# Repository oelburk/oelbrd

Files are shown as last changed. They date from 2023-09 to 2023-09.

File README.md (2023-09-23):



<!-- PROJECT SHIELDS -->
[][contributors-url]
[][forks-url]
[][stars-url]
[][issues-url]
[][license-url]

<!-- PROJECT LOGO -->
<br />
<div align="center">
  <a href="https://github.com/oelburk/oelbrd">
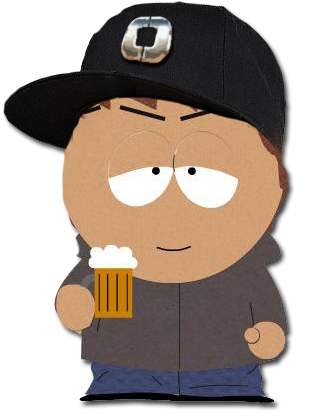
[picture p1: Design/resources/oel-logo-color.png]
    
  </a>

<h3 align="center">OELBRD</h3>

  <p align="center">
    Custom designed keyboard PCB and Firmware
    <br />
    <a href="https://github.com/oelburk/oelbrd/issues">Report Bug</a>
    ·
    <a href="https://github.com/oelburk/oelbrd/issues">Request Feature</a>
  </p>
</div>

<!-- TABLE OF CONTENTS -->
<details>
  <summary>Table of Contents</summary>
  <ol>
    <li>
      <a href="#about-the-project">About The Project</a>
      <ul>
        <li><a href="#built-with">Built With</a></li>
      </ul>
    </li>
    <li>
      <a href="#getting-started">Getting Started (Keymap setup)</a>
      <ul>
        <li><a href="#prerequisites">Prerequisites</a></li>
        <li><a href="#installation">Creating a keymap</a></li>
      </ul>
    </li>
    <li><a href="#contributing">Contributing</a></li>
    <li><a href="#license">License</a></li>
    <li><a href="#acknowledgments">Acknowledgments</a></li>
  </ol>
</details>

<!-- ABOUT THE PROJECT -->
## About The Project

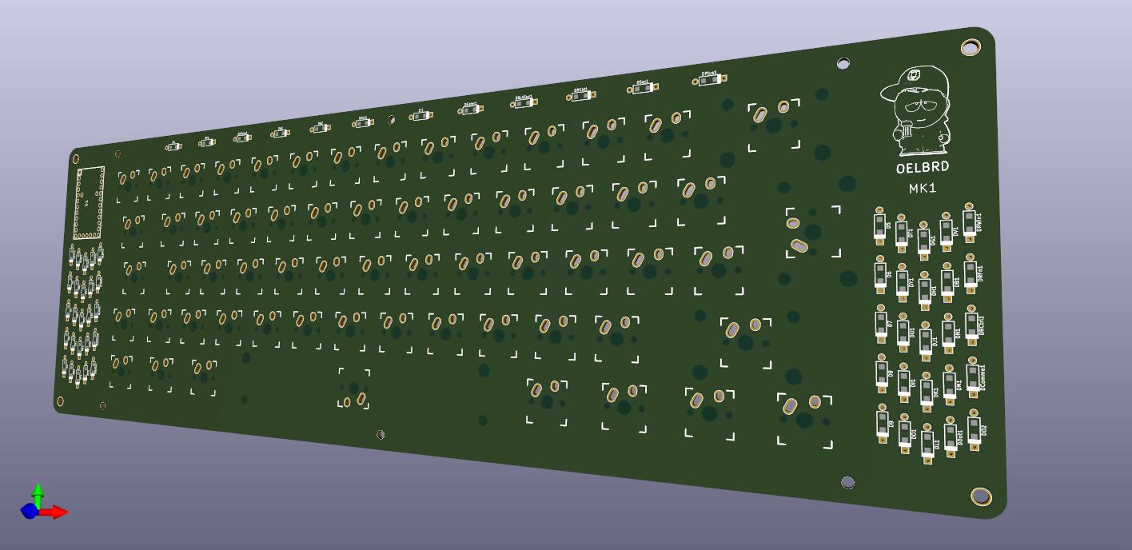
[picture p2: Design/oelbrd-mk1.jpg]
Product Name Screen Shot


Small project containing the PCB design files (KiCad project) along with the source code for different keymaps for my custom designed 60% keyboard.

<p align="right">(<a href="#readme-top">back to top</a>)</p>

### Built With

* [KiCad](https://www.kicad.org/download/windows/)
  * https://github.com/egladman/keebs.pretty
  * https://github.com/tmk/keyboard_parts.pretty
* [QMK](https://qmk.fm/)

<p align="right">(<a href="#readme-top">back to top</a>)</p>

<!-- GETTING STARTED -->
## Getting Started (Keymap setup)

This is an example of how you can create your own keymap for the oelbrd.

### Prerequisites
* Text editor of choice
* [QMK](https://github.com/qmk/qmk_firmware/blob/master/docs/newbs.md)

### Creating a keymap

1. Clone the repo
   ```sh
   git clone https://github.com/oelburk/oelbrd.git
   ```
2. Create new folder in keymaps folder
   ```sh
   mkdir QMK/keymaps/my-keymap
   ```
3. Copy default keymap (optional)
   ```sh
   cp QMK/keymaps/default/keymap.c QMK/keymaps/my-keymap
   ```
4. Edit `keymap.c` with preferred layout
5. Create oelbrd in QMK
   ```sh
   qmk new-keyboard oelbrd
   ```
6. Copy over contents from the QMK folder to new oelbrd directory in QMK repo, usally `../qmk_firmware/keyboards/oelbrd`
7. Compile the new keymap using QMK
   ```sh
   qmk compile -kb oelbrd -kb my-keymap
   ```
8. Flash new layout

### VIA support

There are currently some strange issues with the implemented VIA support, complaining about missing version definitons etc.

To fix this issue:
1. Open `qmk_firware/quantum/via.h`
2. Replace the define `VIA_PROTOCOL_VERSION` at row 62
   ```C
    VIA_PROTOCOL_VERSION 0x0009
   ```
3. Re-compile your keymap.
4. Enjoy VIA!

<p align="right">(<a href="#readme-top">back to top</a>)</p>

<!-- CONTRIBUTING -->
## Contributing

Contributions are what make the open source community such an amazing place to learn, inspire, and create. Any contributions you make are **greatly appreciated**.

If you have a suggestion that would make this better, please fork the repo and create a pull request. You can also simply open an issue with the tag "enhancement".
Don't forget to give the project a star! Thanks again!

1. Fork the Project
2. Create your Feature Branch (`git checkout -b feature/AmazingFeature`)
3. Commit your Changes (`git commit -m 'Add some AmazingFeature'`)
4. Push to the Branch (`git push origin feature/AmazingFeature`)
5. Open a Pull Request

<p align="right">(<a href="#readme-top">back to top</a>)</p>

<!-- LICENSE -->
## License

Distributed under the MIT License. See `LICENSE.txt` for more information.

<p align="right">(<a href="#readme-top">back to top</a>)</p>

<!-- ACKNOWLEDGMENTS -->
## Acknowledgments

* [Shoutout othneildrew for nice README template](https://github.com/othneildrew/Best-README-Template)
* [Swe Mech Keebs Community](http://mekaniskatangentbord.se/)

<p align="right">(<a href="#readme-top">back to top</a>)</p>

<!-- MARKDOWN LINKS & IMAGES -->
<!-- https://www.markdownguide.org/basic-syntax/#reference-style-links -->
[contributors-shield]: https://img.shields.io/github/contributors/oelburk/oelbrd.svg?style=for-the-badge
[contributors-url]: https://github.com/oelburk/oelbrd/graphs/contributors
[forks-shield]: https://img.shields.io/github/forks/oelburk/oelbrd.svg?style=for-the-badge
[forks-url]: https://github.com/oelburk/oelbrd/network/members
[stars-shield]: https://img.shields.io/github/stars/oelburk/oelbrd.svg?style=for-the-badge
[stars-url]: https://github.com/oelburk/oelbrd/stargazers
[issues-shield]: https://img.shields.io/github/issues/oelburk/oelbrd.svg?style=for-the-badge
[issues-url]: https://github.com/oelburk/oelbrd/issues
[license-shield]: https://img.shields.io/github/license/oelburk/oelbrd.svg?style=for-the-badge
[license-url]: https://github.com/oelburk/oelbrd/blob/master/LICENSE.txt
[linkedin-shield]: https://img.shields.io/badge/-LinkedIn-black.svg?style=for-the-badge&logo=linkedin&colorB=555
[linkedin-url]: https://linkedin.com/in/linkedin_username
[product-screenshot]: Design/oelbrd-mk1.jpg
[Next.js]: https://img.shields.io/badge/next.js-000000?style=for-the-badge&logo=nextdotjs&logoColor=white
[Next-url]: https://nextjs.org/
[React.js]: https://img.shields.io/badge/React-20232A?style=for-the-badge&logo=react&logoColor=61DAFB
[React-url]: https://reactjs.org/
[Vue.js]: https://img.shields.io/badge/Vue.js-35495E?style=for-the-badge&logo=vuedotjs&logoColor=4FC08D
[Vue-url]: https://vuejs.org/
[Angular.io]: https://img.shields.io/badge/Angular-DD0031?style=for-the-badge&logo=angular&logoColor=white
[Angular-url]: https://angular.io/
[Svelte.dev]: https://img.shields.io/badge/Svelte-4A4A55?style=for-the-badge&logo=svelte&logoColor=FF3E00
[Svelte-url]: https://svelte.dev/
[Laravel.com]: https://img.shields.io/badge/Laravel-FF2D20?style=for-the-badge&logo=laravel&logoColor=white
[Laravel-url]: https://laravel.com
[Bootstrap.com]: https://img.shields.io/badge/Bootstrap-563D7C?style=for-the-badge&logo=bootstrap&logoColor=white
[Bootstrap-url]: https://getbootstrap.com
[JQuery.com]: https://img.shields.io/badge/jQuery-0769AD?style=for-the-badge&logo=jquery&logoColor=white
[JQuery-url]: https://jquery.com

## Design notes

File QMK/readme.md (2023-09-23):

# oelbrd

*Custom designed PCB based on a typical GH60*

* Keyboard Maintainer: [Alfred Tång](https://github.com/oelburk)
* Hardware Supported: *Custom PCB*
* Hardware Availability: *Reach out to me on the Swedish Mech Discord - [Swe Mech Keebs Community](http://mekaniskatangentbord.se/)*

Make example for this keyboard (after setting up your build environment):

    make oelbrd:default

Flashing example for this keyboard:

    make oelbrd:default:flash

See the [build environment setup](https://docs.qmk.fm/#/getting_started_build_tools) and the [make instructions](https://docs.qmk.fm/#/getting_started_make_guide) for more information. Brand new to QMK? Start with our [Complete Newbs Guide](https://docs.qmk.fm/#/newbs).

## Bootloader

Enter the bootloader in 3 ways:

* **Bootmagic reset**: Hold down the key at (0,0) in the matrix (usually the top left key or Escape) and plug in the keyboard
* **Physical reset button**: Briefly press the button on the back of the PCB - some may have pads you must short instead
* **Keycode in layout**: Press the key mapped to `QK_BOOT` if it is available

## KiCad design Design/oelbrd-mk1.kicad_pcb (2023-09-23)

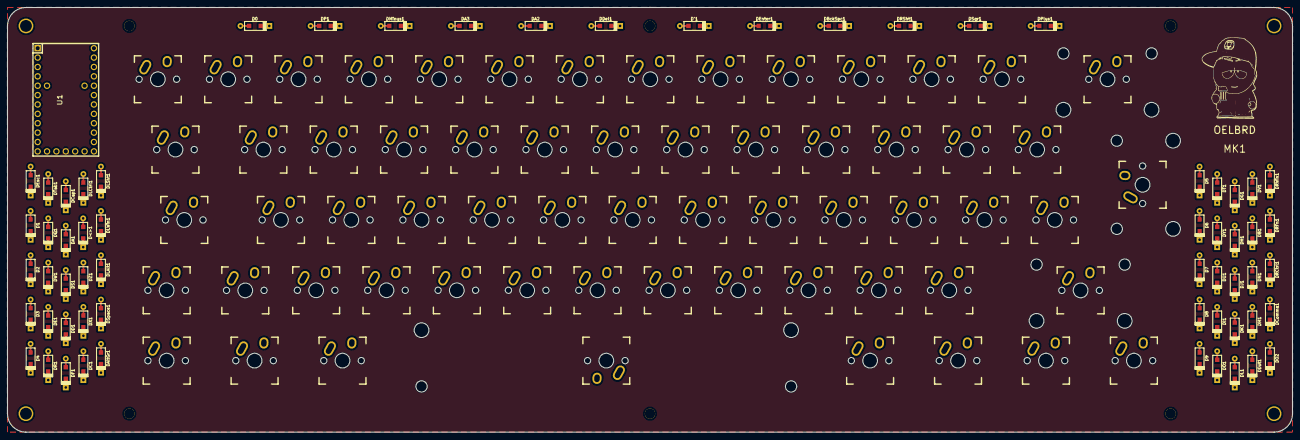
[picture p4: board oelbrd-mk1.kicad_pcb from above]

Board: 2 copper layers, 348.0 x 115.0 mm, 135 parts (0 on the bottom side), 82 nets, no tracks yet.

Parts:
D0, D1, D2, D3, D4, D5, D6, D7, D8, D9: D; D_SOD123_axial
D'1: D; D_SOD123_axial
D<>1: D; D_SOD123_axial
DA1, DA2, DA3: D; D_SOD123_axial
DAltGr1: D; D_SOD123_axial
DB1: D; D_SOD123_axial
DBckSpc1: D; D_SOD123_axial
DC1: D; D_SOD123_axial
DCap1: D; D_SOD123_axial
DComma1: D; D_SOD123_axial
DD1: D; D_SOD123_axial
DDel1: D; D_SOD123_axial
DDot1: D; D_SOD123_axial
DE1: D; D_SOD123_axial
DEnter1: D; D_SOD123_axial
DEsc1: D; D_SOD123_axial
DF1: D; D_SOD123_axial
DG1: D; D_SOD123_axial
DH1: D; D_SOD123_axial
DI1: D; D_SOD123_axial
DJ1: D; D_SOD123_axial
DK1: D; D_SOD123_axial
DL1: D; D_SOD123_axial
DLAlt1: D; D_SOD123_axial
DLCtrl1: D; D_SOD123_axial
DLSht1: D; D_SOD123_axial
DLWin1: D; D_SOD123_axial
DM1: D; D_SOD123_axial
DMinus1: D; D_SOD123_axial
DN1: D; D_SOD123_axial
DO1, DO2: D; D_SOD123_axial
DP1: D; D_SOD123_axial
DPlus1: D; D_SOD123_axial
DQ1: D; D_SOD123_axial
DR1: D; D_SOD123_axial
DRCtrl1: D; D_SOD123_axial
DRFn1: D; D_SOD123_axial
DRSht1: D; D_SOD123_axial
DRWin1: D; D_SOD123_axial
DS1: D; D_SOD123_axial
DSpace1: D; D_SOD123_axial
DSqr1: D; D_SOD123_axial
DT1: D; D_SOD123_axial
DTab1: D; D_SOD123_axial
DU1: D; D_SOD123_axial
DV1: D; D_SOD123_axial
DW1: D; D_SOD123_axial
DX1: D; D_SOD123_axial
DY1: D; D_SOD123_axial
DZ1: D; D_SOD123_axial
HOLE_M2.6, HOLE_M2.6#2, HOLE_M2.6#3, HOLE_M2.6#4, HOLE_M2.6#5, HOLE_M2.6#6: VAL**; HOLE_M2.6
HOLE_M3, HOLE_M3#2, HOLE_M3#3, HOLE_M3#4: VAL**; HOLE_M3
K0, K1, K2, K3, K4, K5, K6, K7, K8, K9: KEYSW; Mx_Alps_100
K'1: KEYSW; Mx_Alps_100
K<>1: KEYSW; Mx_Alps_100
KA1, KA2, KA3: KEYSW; Mx_Alps_100
KAltGr1: KEYSW; Mx_Alps_125
KB1: KEYSW; Mx_Alps_100
KBckSpc1: KEYSW; Mx_Alps_200
KC1: KEYSW; Mx_Alps_100
KCap1: KEYSW; Mx_Alps_175
KComma1: KEYSW; Mx_Alps_100
KD1: KEYSW; Mx_Alps_100
KDel1: KEYSW; Mx_Alps_100
KDot1: KEYSW; Mx_Alps_100
KE1: KEYSW; Mx_Alps_100
KEnter1: KEYSW; Mx_Alps_200
KEsc1: KEYSW; Mx_Alps_100
KF1: KEYSW; Mx_Alps_100
KG1: KEYSW; Mx_Alps_100
KH1: KEYSW; Mx_Alps_100
KI1: KEYSW; Mx_Alps_100
KJ1: KEYSW; Mx_Alps_100
KK1: KEYSW; Mx_Alps_100
KL1: KEYSW; Mx_Alps_100
KLAlt1: KEYSW; Mx_Alps_125
KLCtrl1: KEYSW; Mx_Alps_125
KLSht1: KEYSW; Mx_Alps_125
KLWin1: KEYSW; Mx_Alps_125
KM1: KEYSW; Mx_Alps_100
KMinus1: KEYSW; Mx_Alps_100
KN1: KEYSW; Mx_Alps_100
KO1, KO2: KEYSW; Mx_Alps_100
KP1: KEYSW; Mx_Alps_100
KPlus1: KEYSW; Mx_Alps_100
KQ1: KEYSW; Mx_Alps_100
KR1: KEYSW; Mx_Alps_100
KRCtrl1: KEYSW; Mx_Alps_125
KRFn1: KEYSW; Mx_Alps_125
KRSht1: KEYSW; Mx_Alps_275
KRWin1: KEYSW; Mx_Alps_125
KS1: KEYSW; Mx_Alps_100
KSpace1: KEYSW; Mx_Alps_625
KSqr1: KEYSW; Mx_Alps_100
KT1: KEYSW; Mx_Alps_100
KTab1: KEYSW; Mx_Alps_150
KU1: KEYSW; Mx_Alps_100
KV1: KEYSW; Mx_Alps_100
KW1: KEYSW; Mx_Alps_100
KX1: KEYSW; Mx_Alps_100
KY1: KEYSW; Mx_Alps_100
KZ1: KEYSW; Mx_Alps_100
U1: TEENSY2.0; Teensy_20

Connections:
/col0: KCap1.1, KEsc1.1, KLCtrl1.1, KLSht1.1, KTab1.1, U1.21
/col1: K1.1, K<>1.1, KA1.1, KLWin1.1, KQ1.1, U1.22
/col2: K2.1, KLAlt1.1, KS1.1, KW1.1, KZ1.1, U1.6
/col3: K3.1, KD1.1, KE1.1, KSpace1.1, KX1.1, U1.11
/col4: K4.1, KAltGr1.1, KC1.1, KF1.1, KR1.1, U1.12
/col5: K5.1, KG1.1, KRWin1.1, KT1.1, KV1.1, U1.7
/col6: K6.1, KB1.1, KH1.1, KRFn1.1, KY1.1, U1.8
/col7: K7.1, KJ1.1, KN1.1, KRCtrl1.1, KU1.1, U1.9
/col8: K8.1, KI1.1, KK1.1, KM1.1, U1.10
/col9: K9.1, KComma1.1, KL1.1, KO1.1, U1.17
/col10: K0.1, KDot1.1, KO2.1, KP1.1, U1.13
/col11: KA2.1, KA3.1, KMinus1.1, KPlus1.1, U1.19
/col12: K'1.1, KDel1.1, KRSht1.1, KSqr1.1, U1.31
/col13: KBckSpc1.1, KEnter1.1, U1.28
/row0: D0.1, D1.1, D2.1, D3.1, D4.1, D5.1, D6.1, D7.1, D8.1, D9.1, DBckSpc1.1, DDel1.1, DEsc1.1, DPlus1.1, U1.2
/row1: DA2.1, DE1.1, DEnter1.1, DI1.1, DO1.1, DP1.1, DQ1.1, DR1.1, DSqr1.1, DT1.1, DTab1.1, DU1.1, DW1.1, DY1.1, U1.3
/row2: D'1.1, DA1.1, DA3.1, DCap1.1, DD1.1, DF1.1, DG1.1, DH1.1, DJ1.1, DK1.1, DL1.1, DO2.1, DS1.1, U1.4
/row3: D<>1.1, DB1.1, DC1.1, DComma1.1, DDot1.1, DLSht1.1, DM1.1, DMinus1.1, DN1.1, DRSht1.1, DV1.1, DX1.1, DZ1.1, U1.5
/row4: DAltGr1.1, DLAlt1.1, DLCtrl1.1, DLWin1.1, DRCtrl1.1, DRFn1.1, DRWin1.1, DSpace1.1, U1.20
GND: U1.1, U1.15
unnamed: D0.2, K0.2
unnamed: D1.2, K1.2
unnamed: D2.2, K2.2
unnamed: D3.2, K3.2
unnamed: D4.2, K4.2
unnamed: D5.2, K5.2
unnamed: D6.2, K6.2
unnamed: D7.2, K7.2
unnamed: D8.2, K8.2
unnamed: D9.2, K9.2
unnamed: D'1.2, K'1.2
unnamed: D<>1.2, K<>1.2
unnamed: DA1.2, KA1.2
unnamed: DA2.2, KA2.2
unnamed: DA3.2, KA3.2
unnamed: DAltGr1.2, KAltGr1.2
unnamed: DB1.2, KB1.2
unnamed: DBckSpc1.2, KBckSpc1.2
unnamed: DC1.2, KC1.2
unnamed: DCap1.2, KCap1.2
unnamed: DComma1.2, KComma1.2
unnamed: DD1.2, KD1.2
unnamed: DDel1.2, KDel1.2
unnamed: DDot1.2, KDot1.2
unnamed: DE1.2, KE1.2
unnamed: DEnter1.2, KEnter1.2
unnamed: DEsc1.2, KEsc1.2
unnamed: DF1.2, KF1.2
unnamed: DG1.2, KG1.2
unnamed: DH1.2, KH1.2
unnamed: DI1.2, KI1.2
unnamed: DJ1.2, KJ1.2
unnamed: DK1.2, KK1.2
unnamed: DL1.2, KL1.2
unnamed: DLAlt1.2, KLAlt1.2
unnamed: DLCtrl1.2, KLCtrl1.2
unnamed: DLSht1.2, KLSht1.2
unnamed: DLWin1.2, KLWin1.2
unnamed: DM1.2, KM1.2
unnamed: DMinus1.2, KMinus1.2
unnamed: DN1.2, KN1.2
unnamed: DO1.2, KO1.2
unnamed: DO2.2, KO2.2
unnamed: DP1.2, KP1.2
unnamed: DPlus1.2, KPlus1.2
unnamed: DQ1.2, KQ1.2
unnamed: DR1.2, KR1.2
unnamed: DRCtrl1.2, KRCtrl1.2
unnamed: DRFn1.2, KRFn1.2
unnamed: DRSht1.2, KRSht1.2
unnamed: DRWin1.2, KRWin1.2
unnamed: DS1.2, KS1.2
unnamed: DSpace1.2, KSpace1.2
unnamed: DSqr1.2, KSqr1.2
unnamed: DT1.2, KT1.2
unnamed: DTab1.2, KTab1.2
unnamed: DU1.2, KU1.2
unnamed: DV1.2, KV1.2
unnamed: DW1.2, KW1.2
unnamed: DX1.2, KX1.2
unnamed: DY1.2, KY1.2
unnamed: DZ1.2, KZ1.2

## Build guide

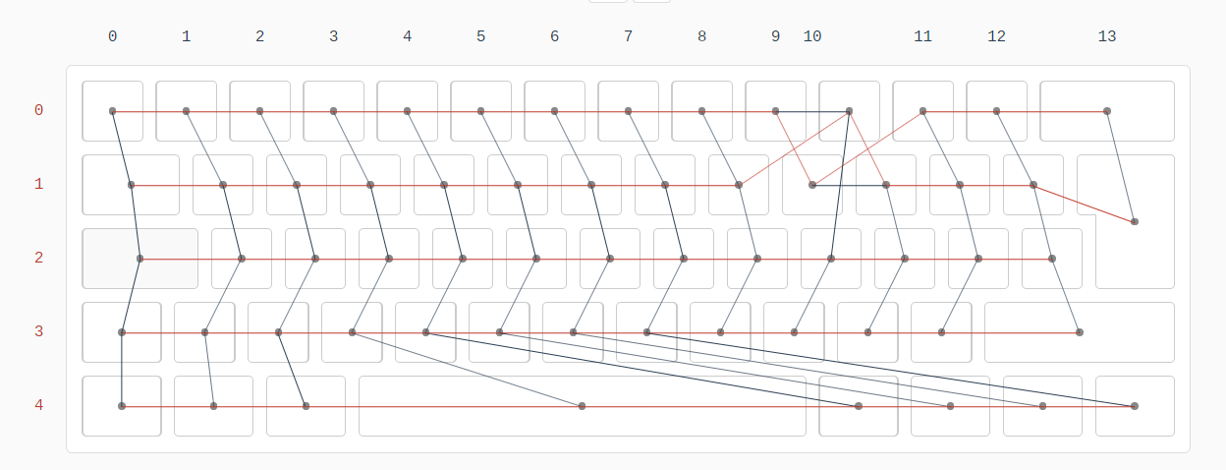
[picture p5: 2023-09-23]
Design/wiring_oelbrd-mk1.PNG
